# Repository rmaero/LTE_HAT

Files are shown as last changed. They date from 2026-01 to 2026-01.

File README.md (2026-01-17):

4G HAT para Raspberry Pi, Diseño completo de un HAT compatible con Raspberry Pi que integra comunicaciones celulares 4G/LTE. Hecho especialmente para usar como companion computer en y comunicarse con un PixHawk en un UAV (unmanned aerial vehicle).
Desarrollado como proyecto final para la materia Diseño Avanzado de Circuitos Impresos en la Universidad Nacional de Rosario.




Dentro del repositorio se van a encontrar 3 versiones del layout apenas diferentes entre si. Estas iteraciones se hicieron en busqueda de optimizar el espacio y la comodidad de los conectores para el usuario (tener en cuenta que una vez estar montado sobre una Raspberry Pi la cara inferior del HAT no es accesible).

Características

Compatible con estándar Raspberry Pi HAT
Cumple especificaciones mecánicas (65x56mm, mounting holes)
EEPROM de identificación según estándar HAT
Conectores GPIO de 40 pines

Comunicacion UART PixHawk:
Conector JST GH 6 pines para conectar con cable cruzado a GPS2 o TELEM2 del PixHawk Cube Orange. 115200 baudios.

Comunicaciones 4G/LTE:

Módulo celular: SIM7600
Bandas soportadas: [especificar]
Interfaz USB para comandos AT
Conectores SMA/U.FL para antenas externas

Diseño RF de Alta Frecuencia

PCB multicapa: 2 capas (esto fue eleccion adrede como ejercicio academico, porque es mas dificil lograr impedancia controlada con esta distancia entre capas).
Control de impedancia de 50Ω en líneas de RF
Control de impedancia de 90Ω en lineas USB 2.0
Stackup optimizado para señales high-speed
Matching de impedancia en conexiones de antena

Alimentación
Pack de baterias 2S a 9S (de 7V a 35V). Regulador switching para alimentar la Raspberry Pi, segundo regulador switching alimenta el modulo SIM7600.

Tecnologías Utilizadas

Diseño PCB: KiCAD 9
Capas: 2 layers (Ground plane en ambas capas)
Comunicación: USB, UART, SPI, GPIO
Impedancia controlada: 50Ω para trazas RF, 90Ω diferencial para USB

Esquematico principal
Captura de pantalla 2026-01-17 a la(s) 10 48 18
El esquematico completo puede encontrarse en la carpeta del proyecto.

Estado del Proyecto

-Diseño esquemático completo
-Layout PCB con control de impedancia
-Diseño validado en simulación

Estado actual: Proyecto académico completado (2025). Diseño validado, pendiente fabricación y testing.

Licencia
Proyecto académico - Todos los derechos reservados

Contacto
Rodrigo Maero - r.maero@gmail.com

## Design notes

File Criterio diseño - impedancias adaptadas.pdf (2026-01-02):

Antenas de GSM
Por manual del SIM7600, las antenas GSM tienen que tener una impedancia de 50 Ohms. Para lograr esto con 2 layers, cada capa de 2oz de espesor (35 micrones) y 1.5mm de separación, según la simulación de TNT la pista de microstrip tiene que ser de 3mm de espesor.

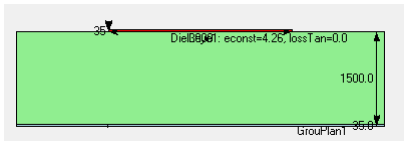
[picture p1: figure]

Characteristic Impedance (Ohms):
For Signal Line ::RectCond1R0= 49.188

No es posible aplicar esto en el layout.
Una opción sería cambiar a 4 layers para tener el plano de retorno más cercano. Con una separación de 250 micrones con el plano de retorno, se necesita una microstrip de 450 micrones de ancho (0.45mm)

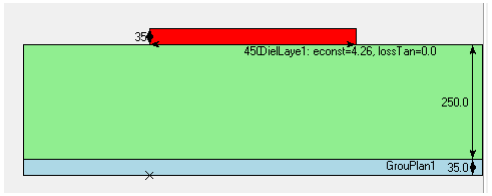
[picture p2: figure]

Characteristic Impedance (Ohms):
For Signal Line ::RectCond1R0= 51.1073

Una opción para mantener el stackup de 2 capas es utilizar una guía de onda coplanar con plano de masa (coplanar waveguide with ground). Se tiene en cuenta la masa rodeando la microstrip con una separación estricta y se rodea con vias al plano de la otra capa para disminuir la impedancia.
https://www.nwengineeringllc.com/article/coplanar-waveguide-design-for-your-rf-pcb.phphttps://electronics.stackexchange.com/questions/87473/how-to-design-a-pcb-to-co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 (https://electronics.stackexchange.com/questions/87473/how-to-design-a-pcb-to-connect-the-gsm-modem-with-50ohm-track-impedance)

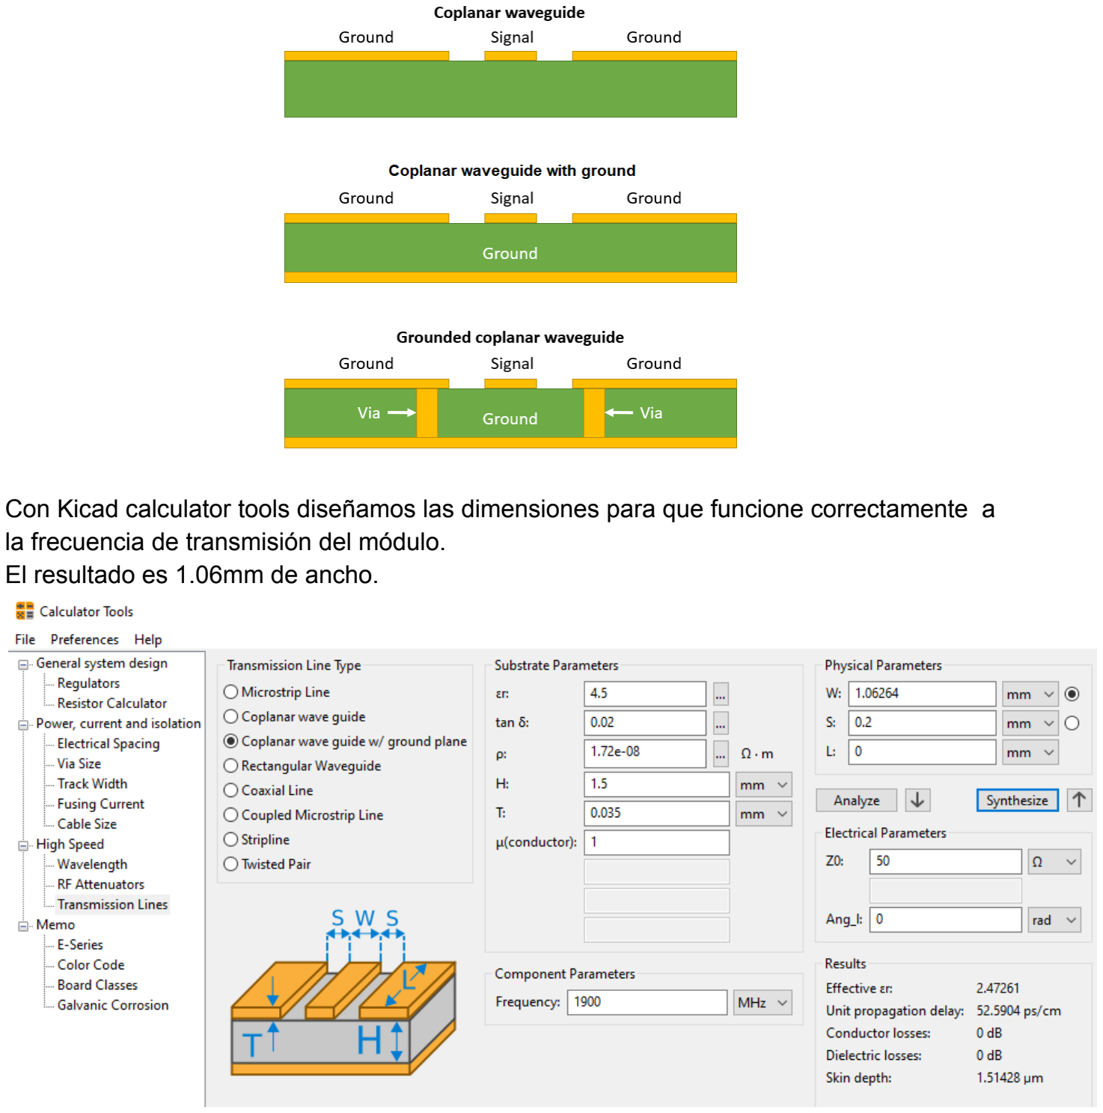
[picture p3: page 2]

Con Kicad calculator tools diseñamos las dimensiones para que funcione correctamente a la frecuencia de transmisión del módulo.
El resultado es 1.06mm de ancho.

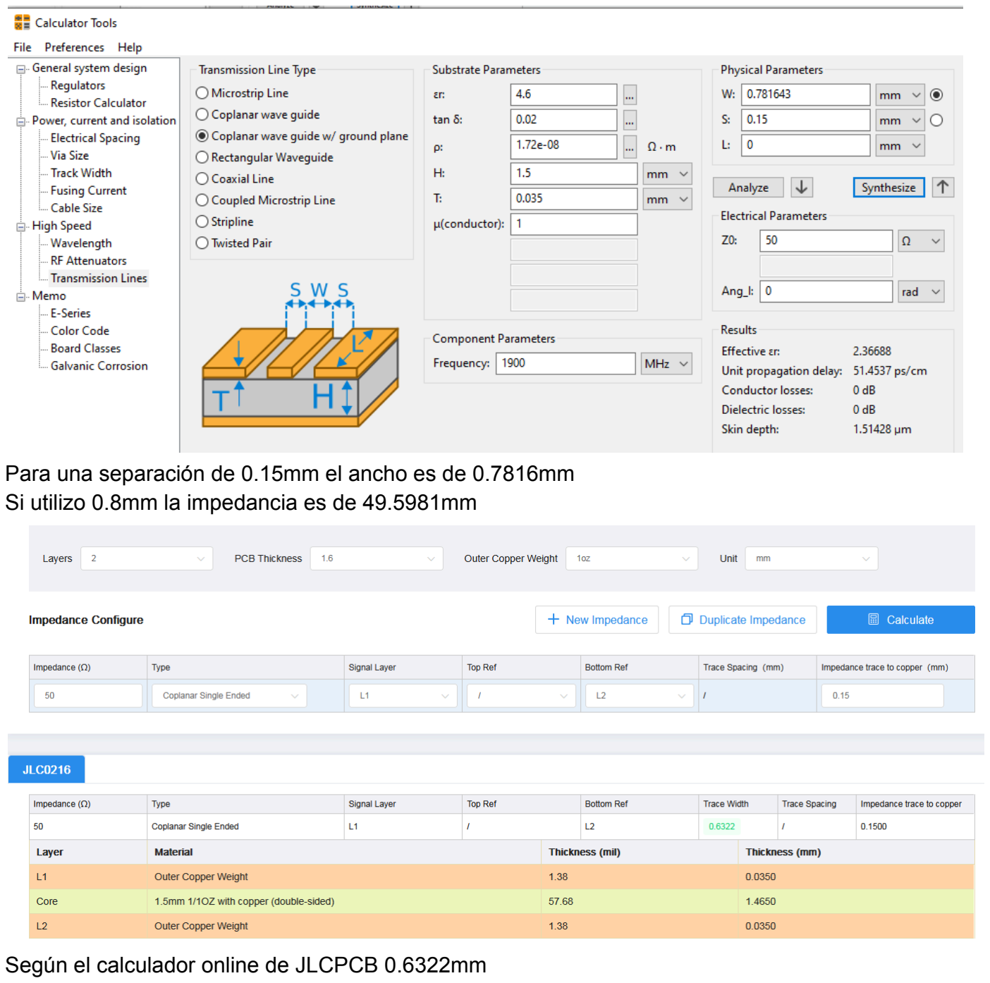
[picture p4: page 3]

Para una separación de 0.15mm el ancho es de 0.7816mm Si utilizo 0.8mm la impedancia es de 49.5981mm

Según el calculador online de JLCPCB 0.6322mm

Ruteo de la antena:

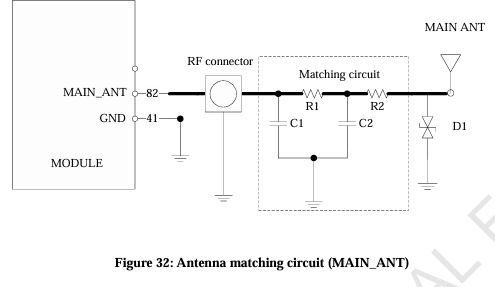
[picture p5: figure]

Del datasheet del modulo SIM7600:
In above figure, the components R1, C1, C2 and R2 are used for antenna matching. By default, the R1, R2 are 0Ω resistors, and the C1, C2 are reserved for tuning.

Se rutea un conector de antena secundario (J230) para poder medir la impedancia de la pista, y en caso de ser necesario se agregan los elementos pasivos R230,R231,C230,C231 para ajustar la impedancia a 50 Ohms.

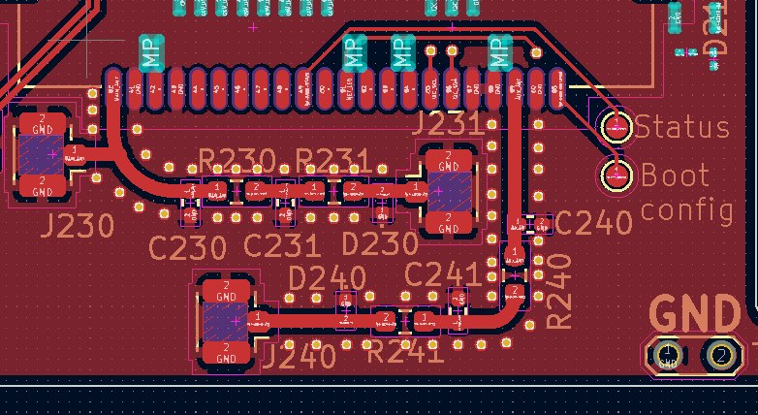
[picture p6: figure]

La línea de transmisión se diseñó curva para evitar ángulos rectos y se agregó via stitching para reducir la impedancia de masa entre las dos capas. No sé qué tan necesarias son estas cosas.

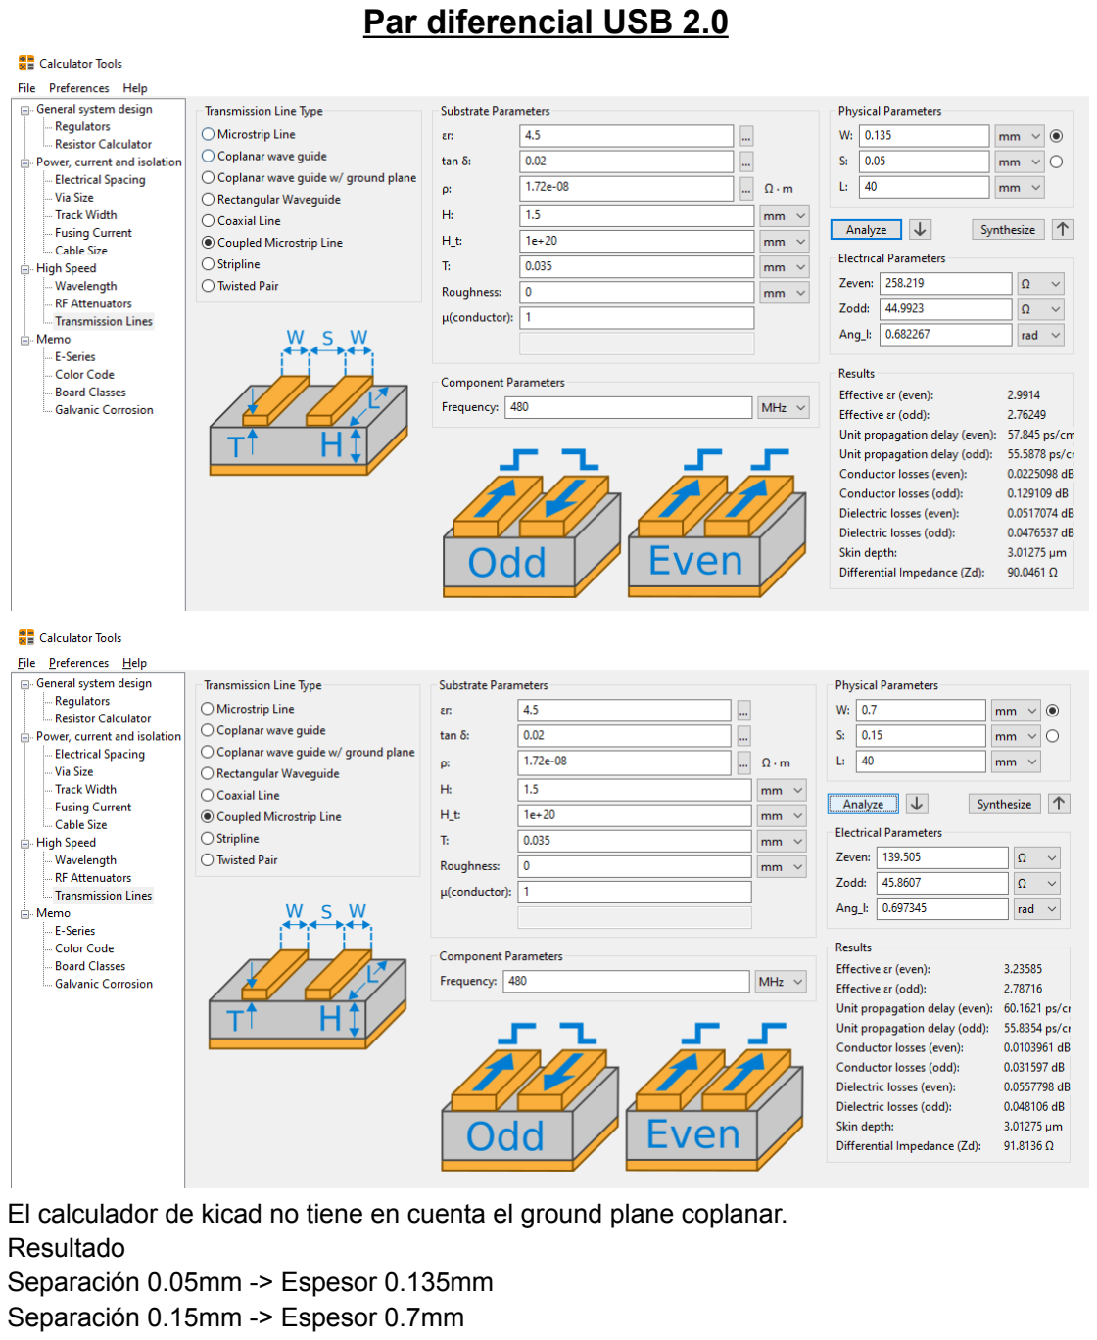
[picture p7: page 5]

### Par diferencial USB 2.0

El calculador de kicad no tiene en cuenta el ground plane coplanar. Resultado
Separación 0.05mm -> Espesor 0.135mm
Separación 0.15mm -> Espesor 0.7mm

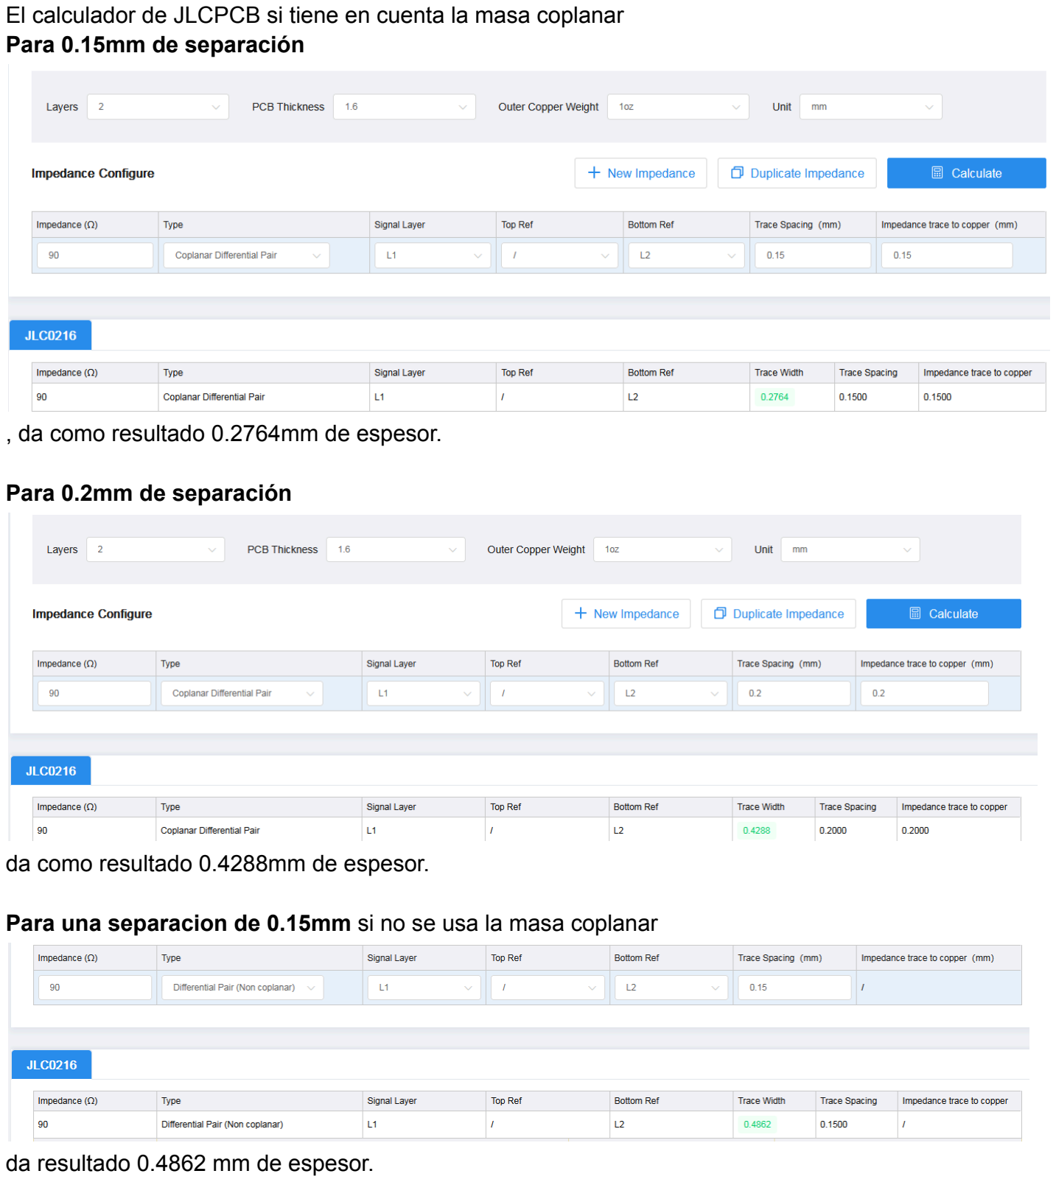
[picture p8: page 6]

El calculador de JLCPCB si tiene en cuenta la masa coplanar Para 0.15mm de separación

, da como resultado 0.2764mm de espesor.

Para 0.2mm de separación

da como resultado 0.4288mm de espesor.

Para una separacion de 0.15mm si no se usa la masa coplanar

da resultado 0.4862 mm de espesor.

Ruteo del par diferencial
Dada la posición elegida del puerto USB en la primer versión, el par diferencial atraviesa discontinuidades en el plano de masa de la capa inferior. Debería tener un plano de masa ininterrumpido para asegurar la impedancia calculada.

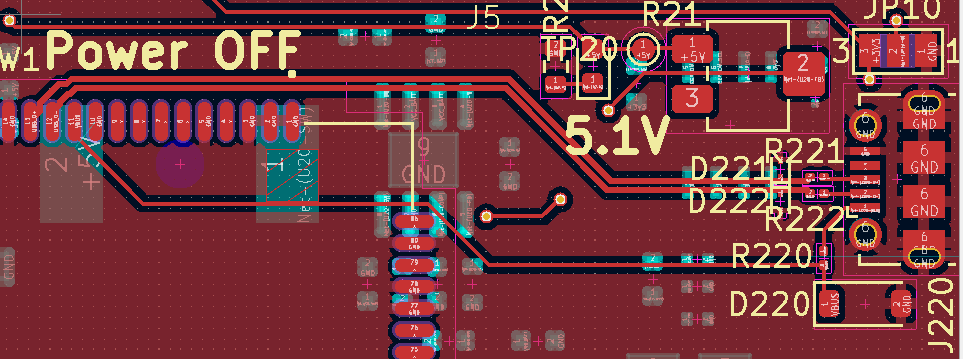
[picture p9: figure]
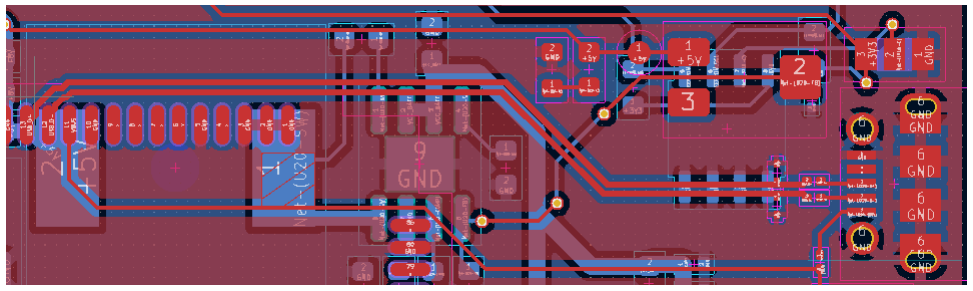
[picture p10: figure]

C

a

m

bia

m

o

s la

p

o

sició

n

d

el p

u

e

r

t

o

al in

f

e

rio

r

d

e la

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
el pla

n

o ininterrumpido.

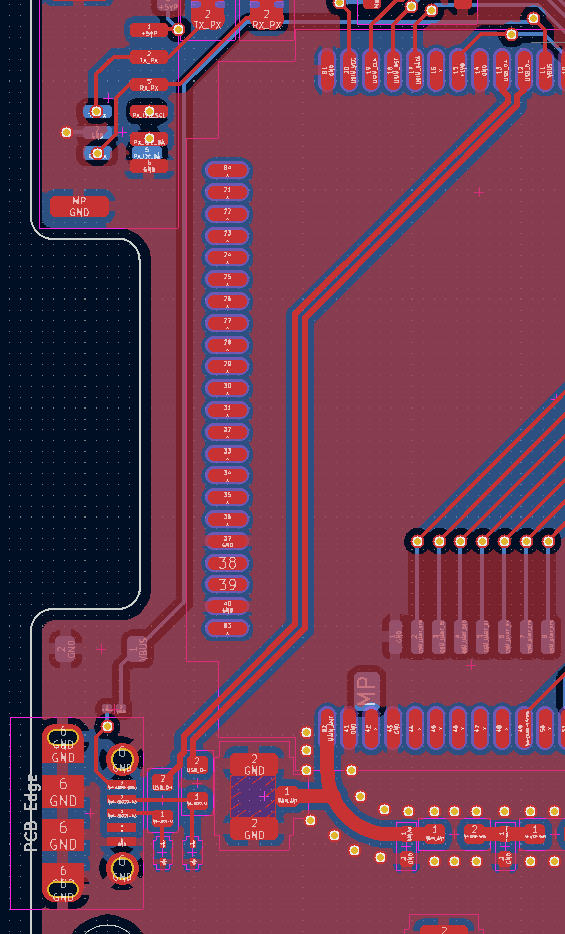
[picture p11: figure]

Version final

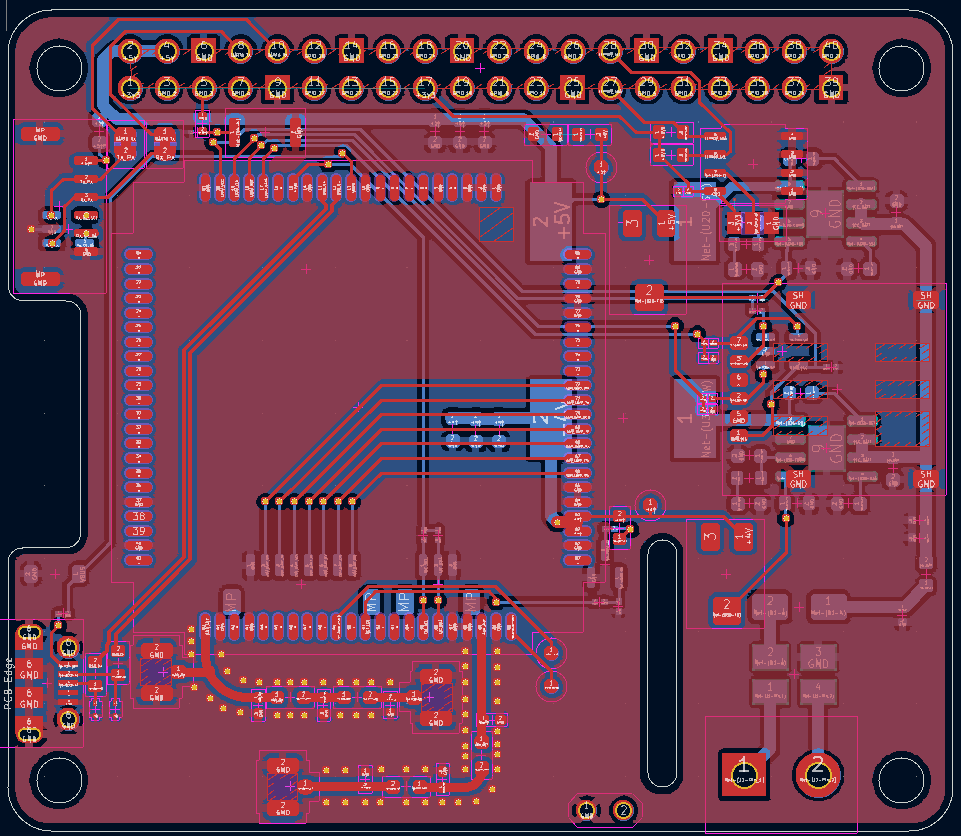
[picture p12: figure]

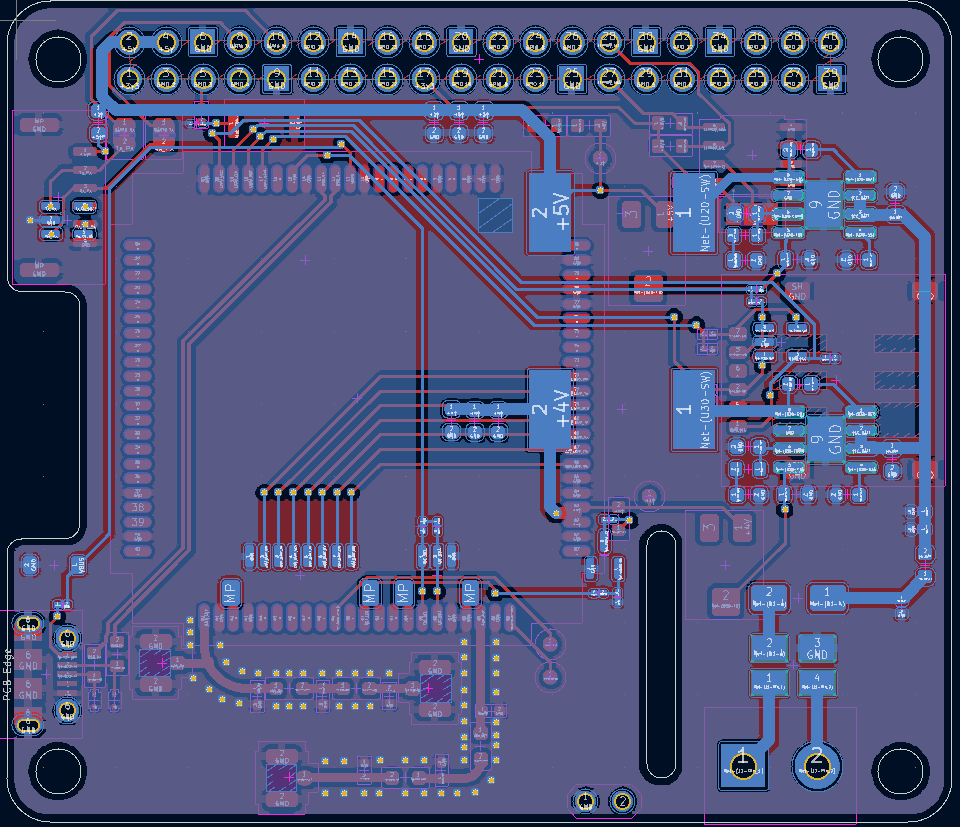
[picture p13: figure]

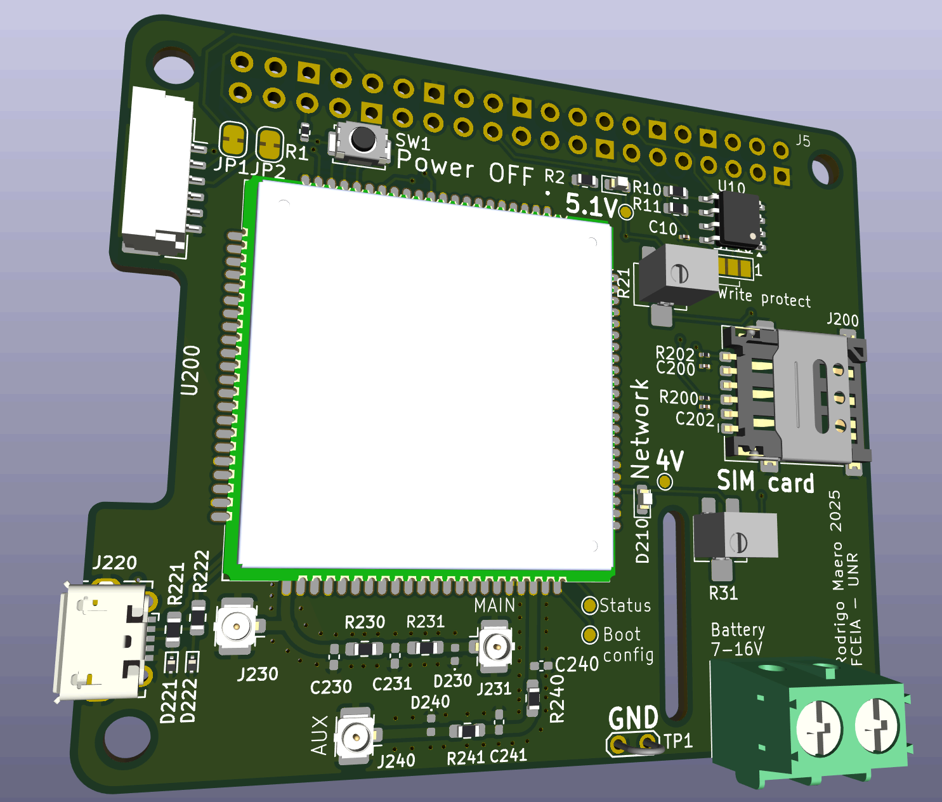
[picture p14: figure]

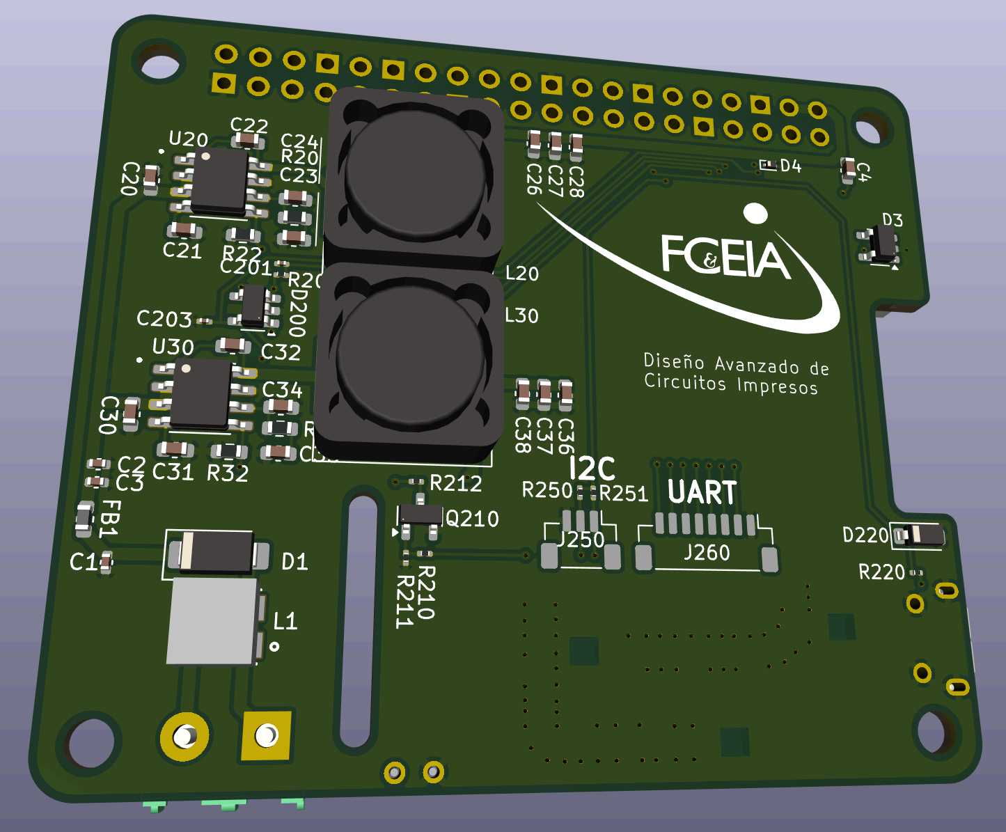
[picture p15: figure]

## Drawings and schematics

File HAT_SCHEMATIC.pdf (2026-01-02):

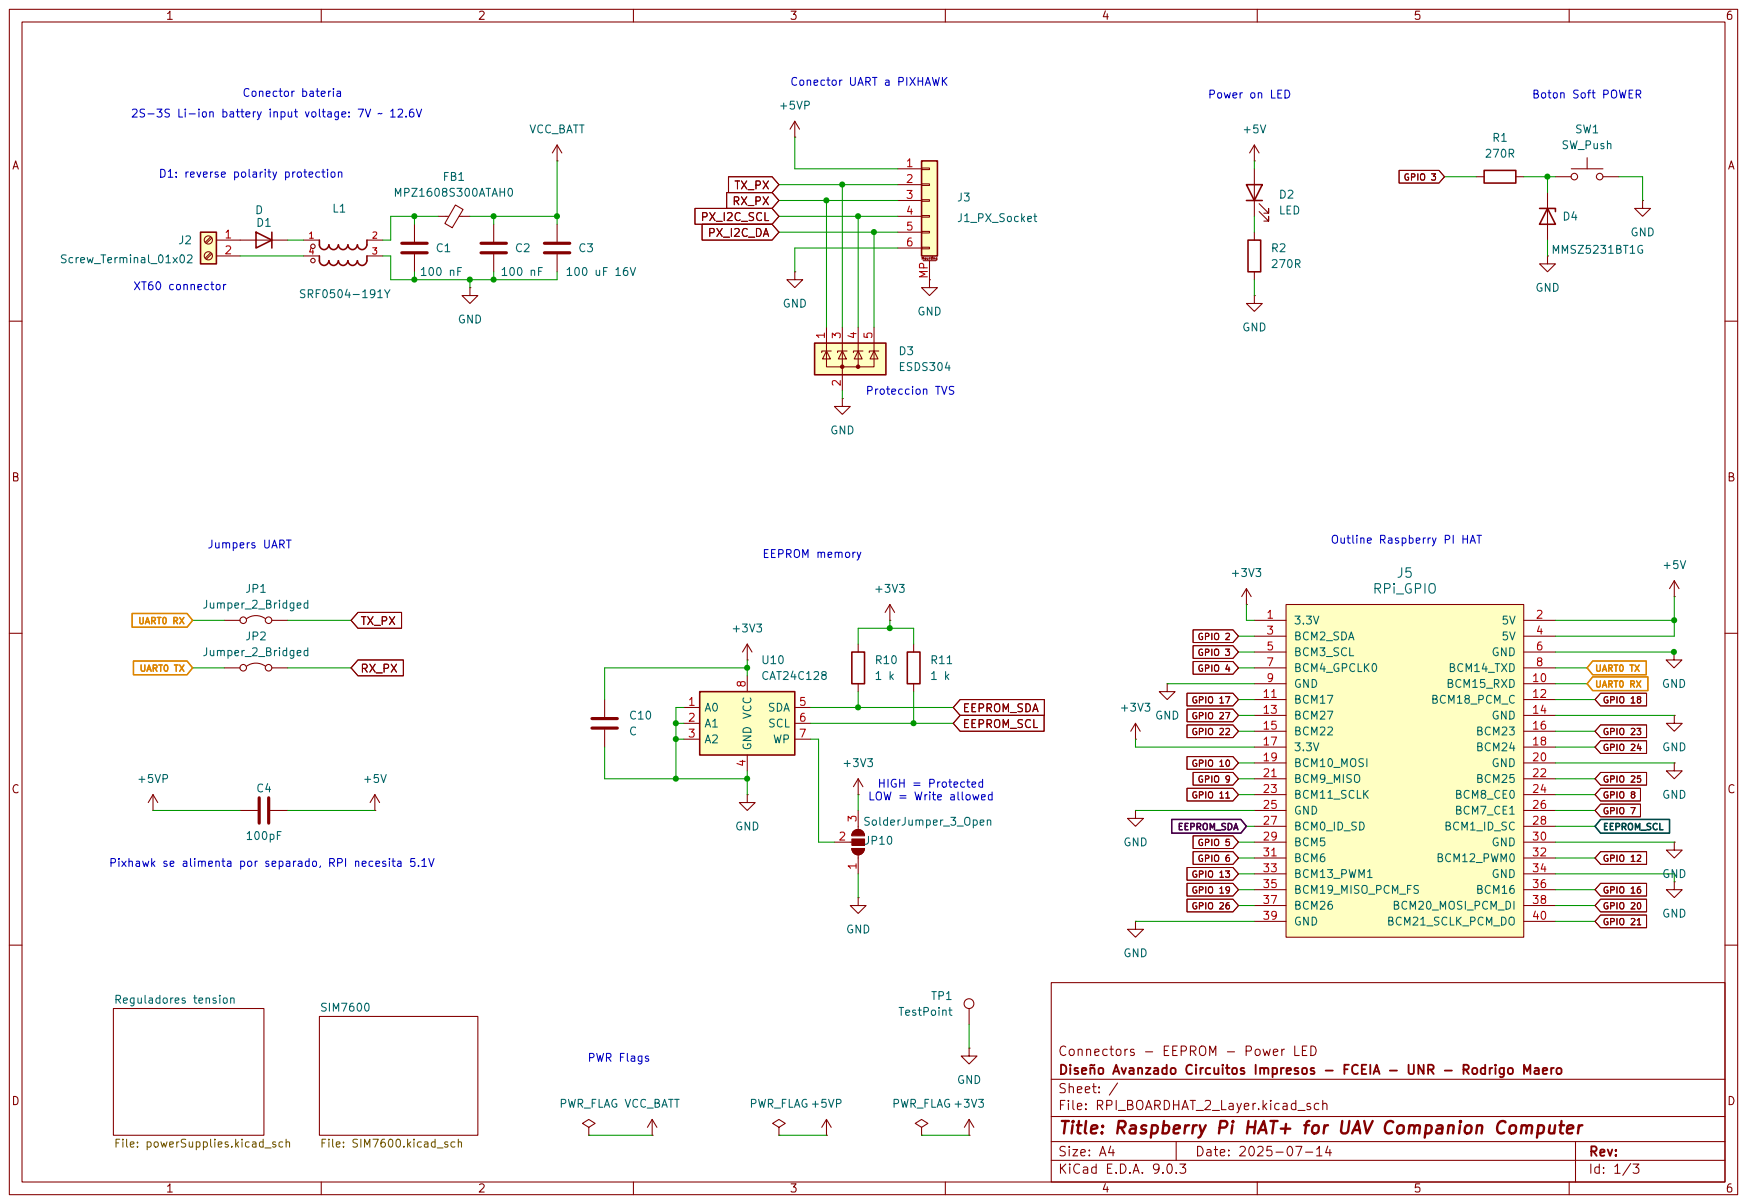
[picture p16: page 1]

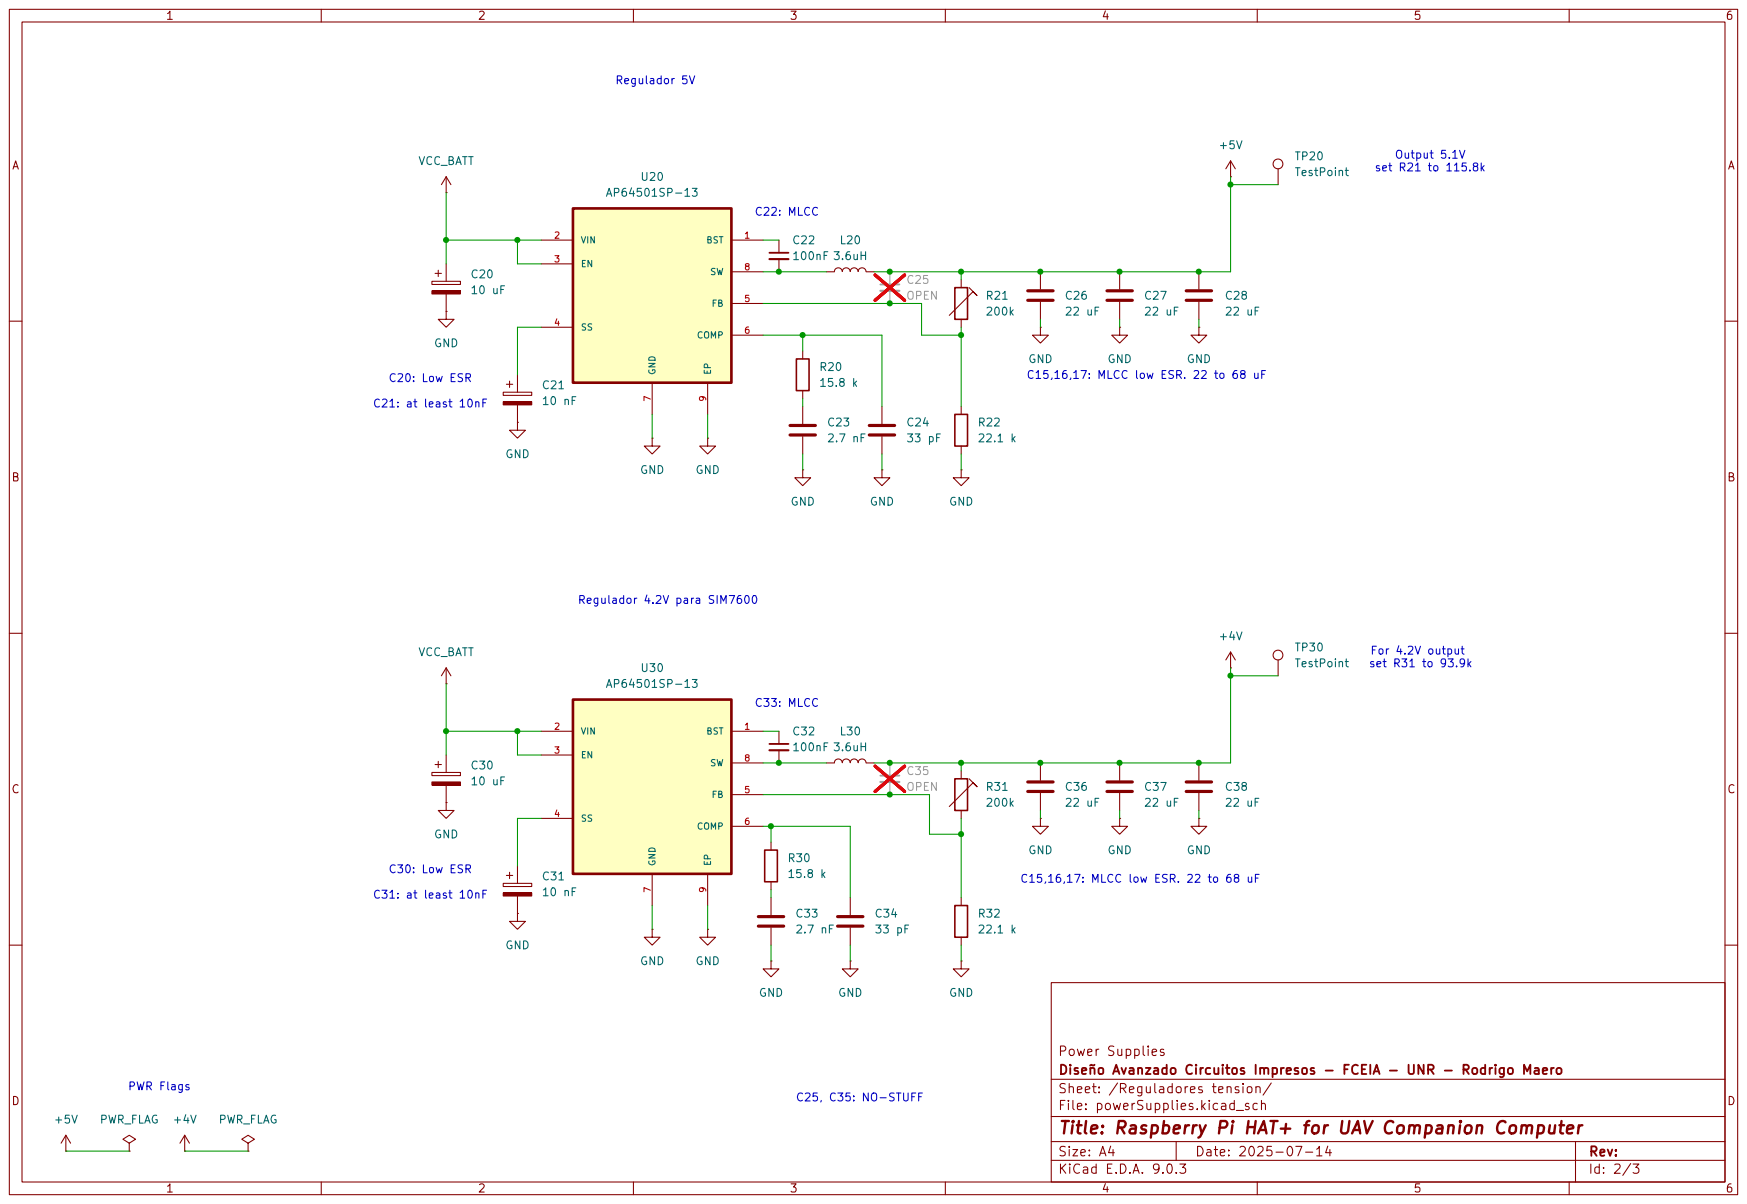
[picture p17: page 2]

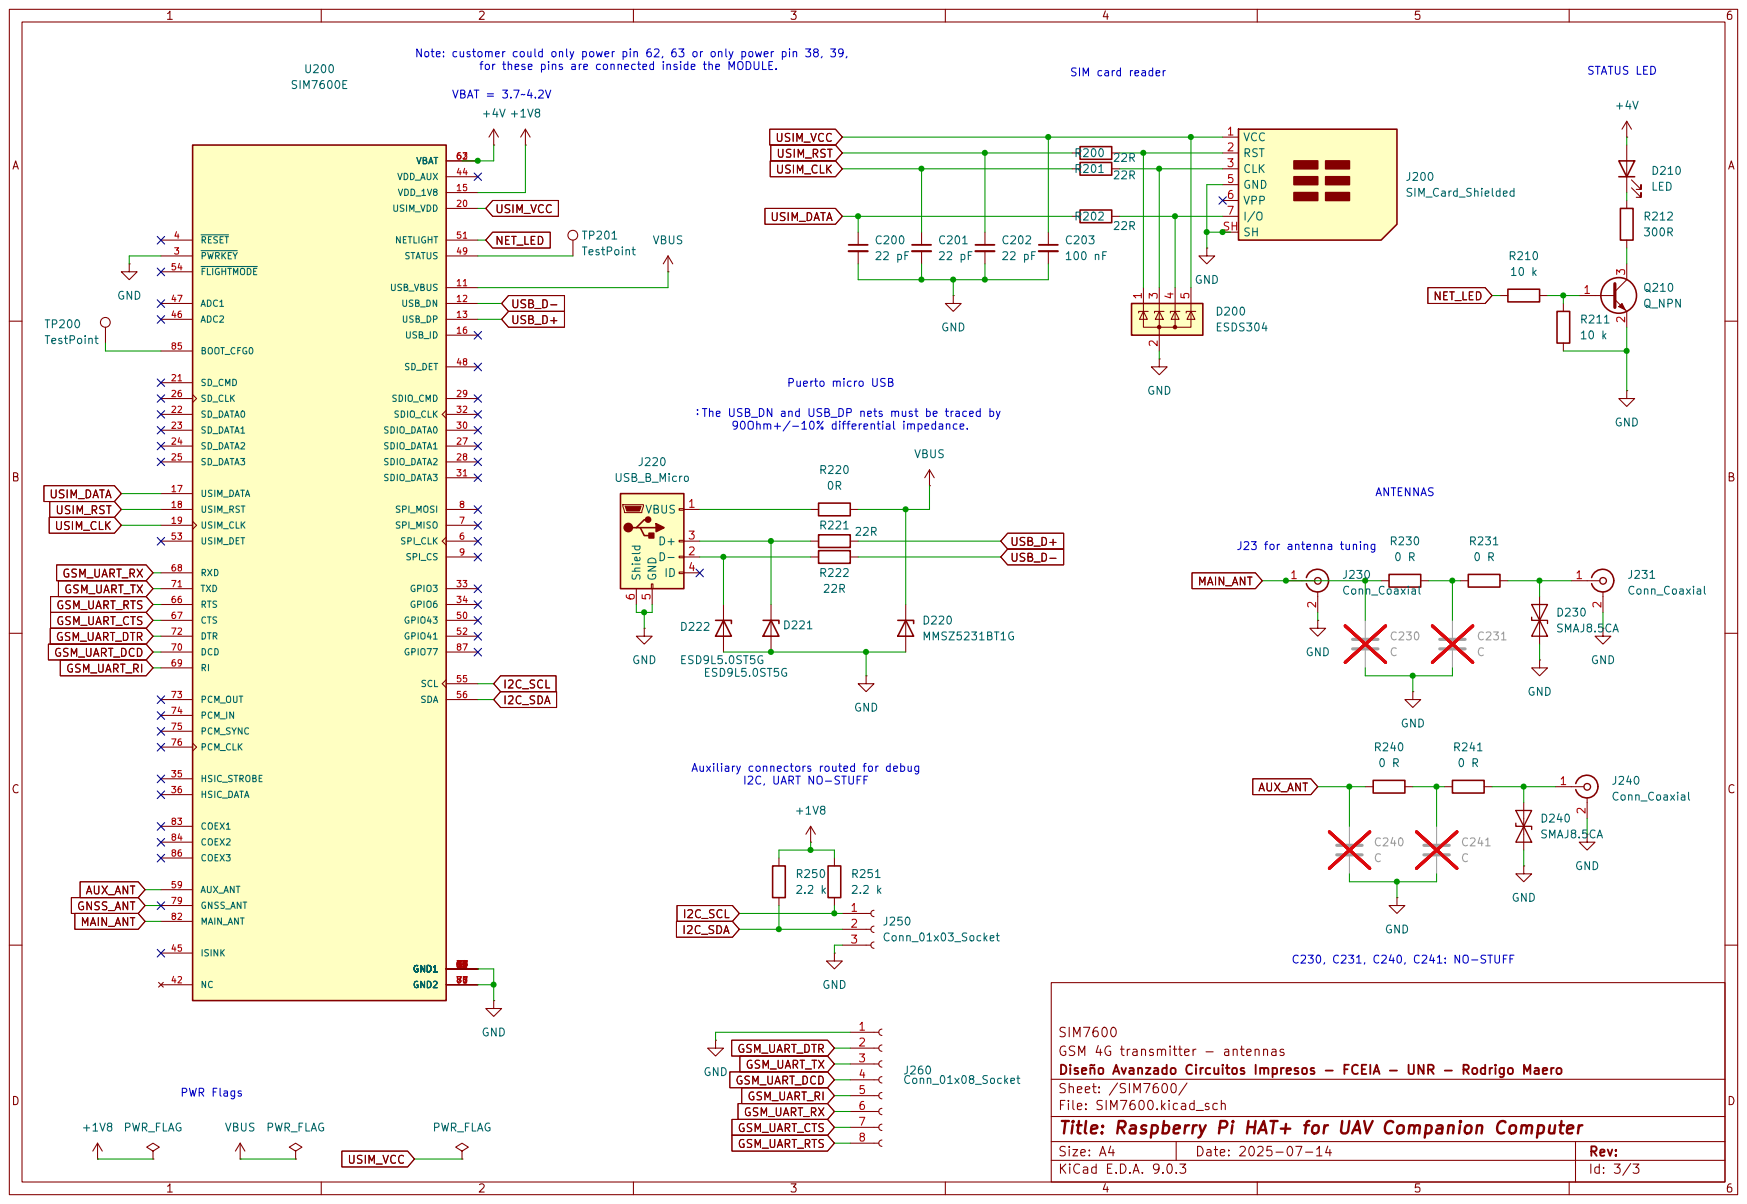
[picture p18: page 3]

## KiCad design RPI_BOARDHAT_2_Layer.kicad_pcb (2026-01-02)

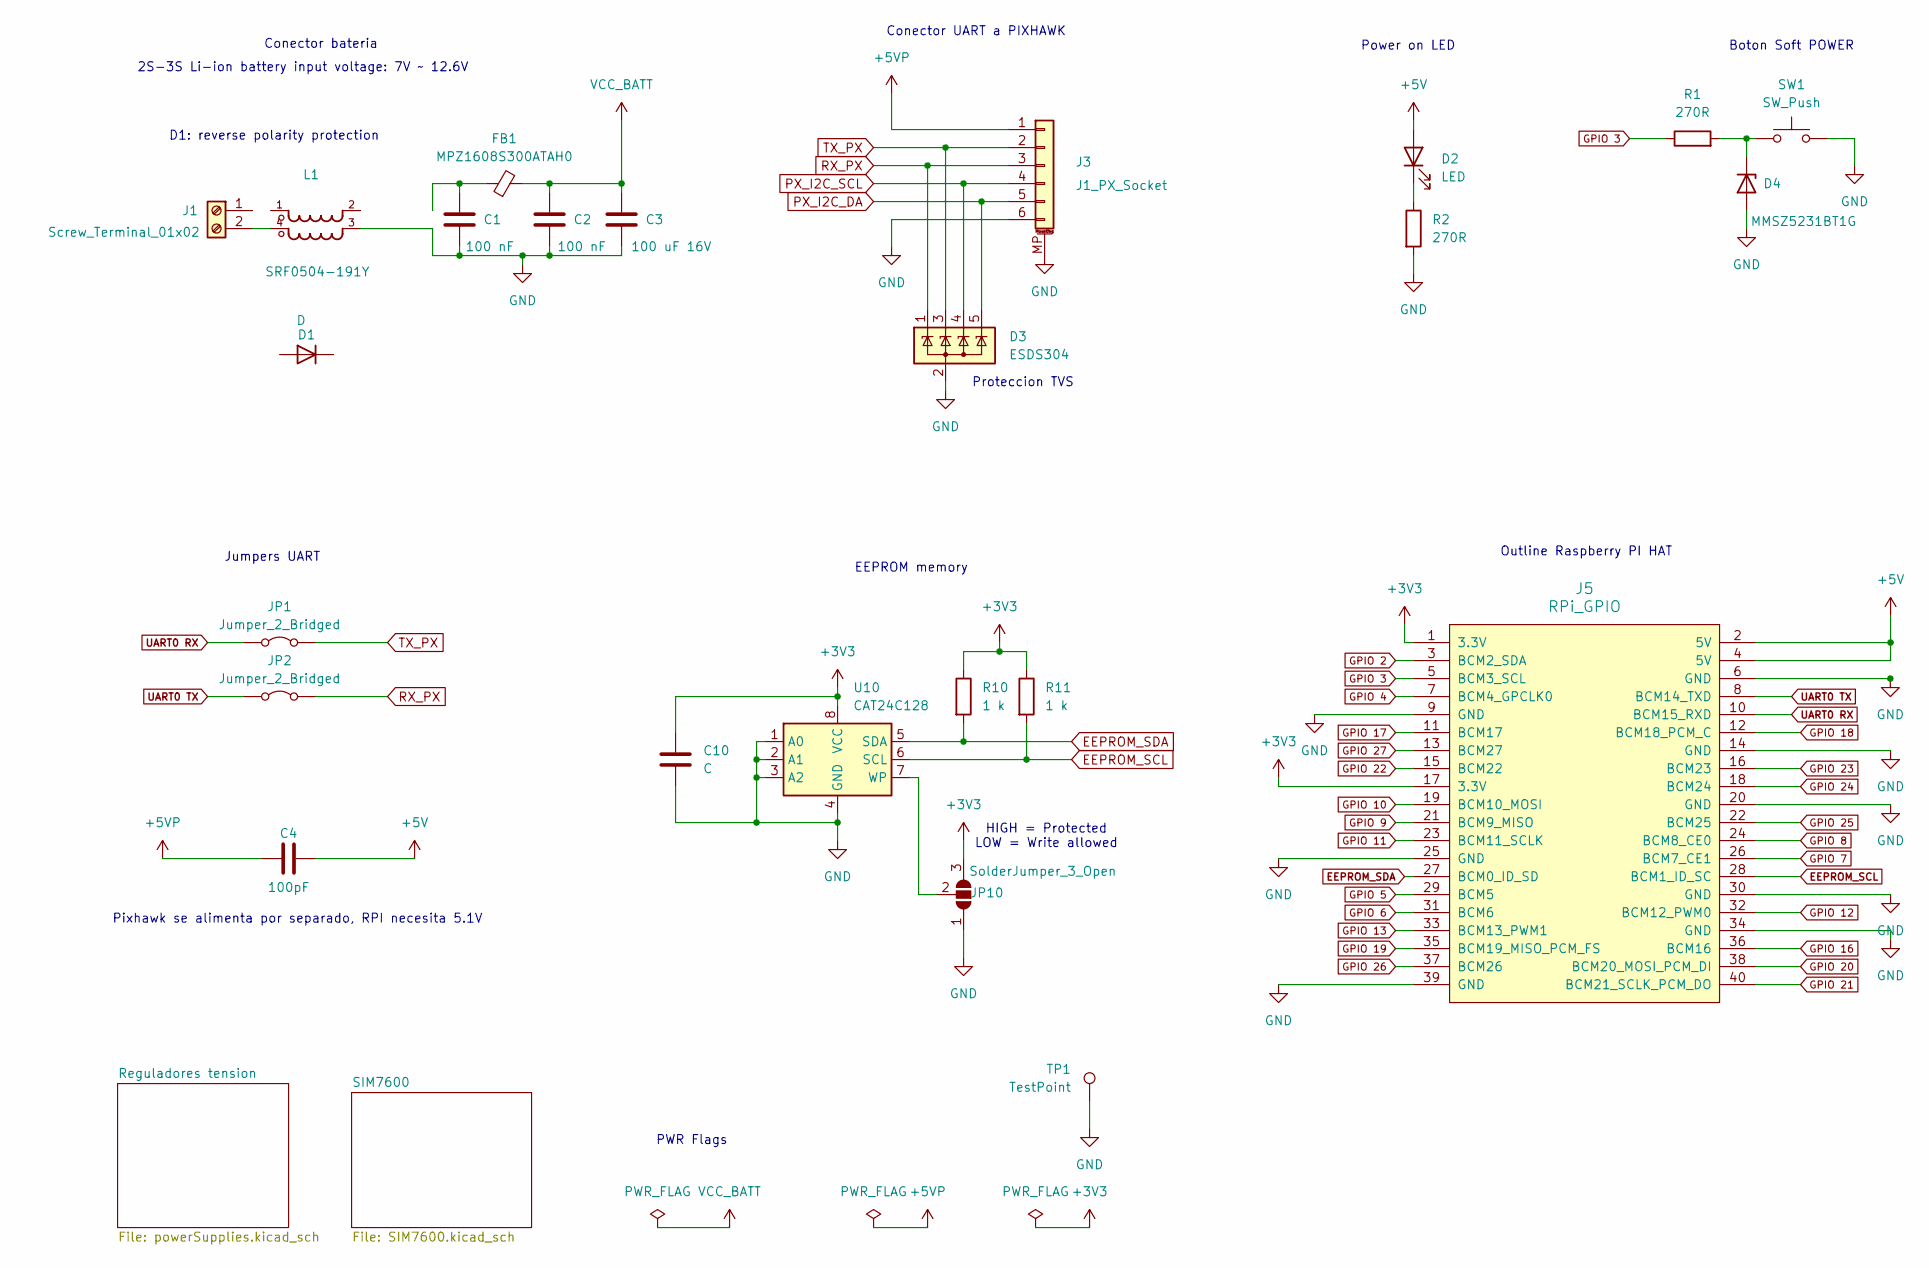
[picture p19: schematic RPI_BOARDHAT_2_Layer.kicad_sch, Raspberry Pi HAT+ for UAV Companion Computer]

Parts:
C1, C2: 100 nF; C_0402_1005Metric
C3: 100 uF 16V; C_0402_1005Metric
C4: 100pF; C_0603_1608Metric
C10: C; C_0201_0603Metric
D1: D; D_SMA
D2: LED; LED_0603_1608Metric
D3: ESDS304; SOT-23-5
D4: MMSZ5231BT1G; D_SOD-923
FB1: MPZ1608S300ATAH0; L_0603_1608Metric
J1: Screw_Terminal_01x02; TerminalBlock_bornier-2_P5.08mm
J3: J1_PX_Socket; JST_GH_SM06B-GHS-TB_1x06-1MP_P1.25mm_Horizontal
J5: RPi_GPIO; RPI_Hat_B+
JP1, JP2: Jumper_2_Bridged; SolderJumper-2_P1.3mm_Bridged_RoundedPad1.0x1.5mm
JP10: SolderJumper_3_Open; SolderJumper-3_P1.3mm_Open_Pad1.0x1.5mm_NumberLabels
L1: SRF0504-191Y; FIL_SRF0504-191Y
R1: 270R; R_0201_0603Metric
R2: 270R; R_0603_1608Metric
R10, R11: 1 k; R_0603_1608Metric
SW1: SW_Push; SW_Push_SPST_NO_Alps_SKRK
TP1: TestPoint; TestPoint_2Pads_Pitch2.54mm_Drill0.8mm
U10: CAT24C128; JEITA_SOIC-8_3.9x4.9mm_P1.27mm

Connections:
+3V3: C10.1, J5.1 (3.3V), J5.17 (3.3V), JP10.3 (B), R10.1, R11.1, U10.8 (VCC)
+5V: C4.1, D2.2 (A), J5.2 (5V), J5.4 (5V); also elsewhere on the board
+5VP: C4.2, J3.1
EEPROM_SCL: J5.28 (BCM1_ID_SC), R11.2, U10.6 (SCL)
EEPROM_SDA: J5.27 (BCM0_ID_SD), R10.2, U10.5 (SDA)
GND: C1.2, C2.2, C3.2, C10.2, D3.2 (A), D4.2 (A), J3.6, J3.MP (MountPin), J5.6 (GND), J5.9 (GND), J5.14 (GND), J5.20 (GND), J5.25 (GND), J5.30 (GND), J5.34 (GND), J5.39 (GND), JP10.1 (A), L1.3, R2.2, SW1.2, TP1.1, U10.1 (A0), U10.2 (A1), U10.3 (A2), U10.4 (GND); also elsewhere on the board
GPIO 2: J5.3 (BCM2_SDA)
GPIO 3: J5.5 (BCM3_SCL), R1.1
GPIO 4: J5.7 (BCM4_GPCLK0)
GPIO 5: J5.29 (BCM5)
GPIO 6: J5.31 (BCM6)
GPIO 7: J5.26 (BCM7_CE1)
GPIO 8: J5.24 (BCM8_CE0)
GPIO 9: J5.21 (BCM9_MISO)
GPIO 10: J5.19 (BCM10_MOSI)
GPIO 11: J5.23 (BCM11_SCLK)
GPIO 12: J5.32 (BCM12_PWM0)
GPIO 13: J5.33 (BCM13_PWM1)
GPIO 16: J5.36 (BCM16)
GPIO 17: J5.11 (BCM17)
GPIO 18: J5.12 (BCM18_PCM_C)
GPIO 19: J5.35 (BCM19_MISO_PCM_FS)
GPIO 20: J5.38 (BCM20_MOSI_PCM_DI)
GPIO 21: J5.40 (BCM21_SCLK_PCM_DO)
GPIO 22: J5.15 (BCM22)
GPIO 23: J5.16 (BCM23)
GPIO 24: J5.18 (BCM24)
GPIO 25: J5.22 (BCM25)
GPIO 26: J5.37 (BCM26)
GPIO 27: J5.13 (BCM27)
unnamed: D1.2 (A), L1.2
unnamed: D2.1 (K), R2.1
unnamed: D4.1 (K), R1.2, SW1.1
unnamed: J1.1, L1.1
unnamed: J1.2, L1.4
unnamed: JP10.2 (C), U10.7 (WP)
PX_I2C_DA: D3.5 (K), J3.5
PX_I2C_SCL: D3.4 (K), J3.4
RX_PX: D3.1 (K), J3.3, JP2.2 (B)
TX_PX: D3.3 (K), J3.2, JP1.2 (B)
UART0 RX: J5.10 (BCM15_RXD), JP1.1 (A)
UART0 TX: J5.8 (BCM14_TXD), JP2.1 (A)
VCC_BATT: C2.1, C3.1, FB1.2; also elsewhere on the board

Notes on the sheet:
2S-3S Li-ion battery input voltage: 7V ~ 12.6V
Proteccion TVS
PWR Flags
Pixhawk se alimenta por separado, RPI necesita 5.1V
D1: reverse polarity protection
EEPROM memory
Outline Raspberry PI HAT
Conector UART a PIXHAWK
Jumpers UART
HIGH = Protected LOW = Write allowed
Boton Soft POWER
Conector bateria
Power on LED

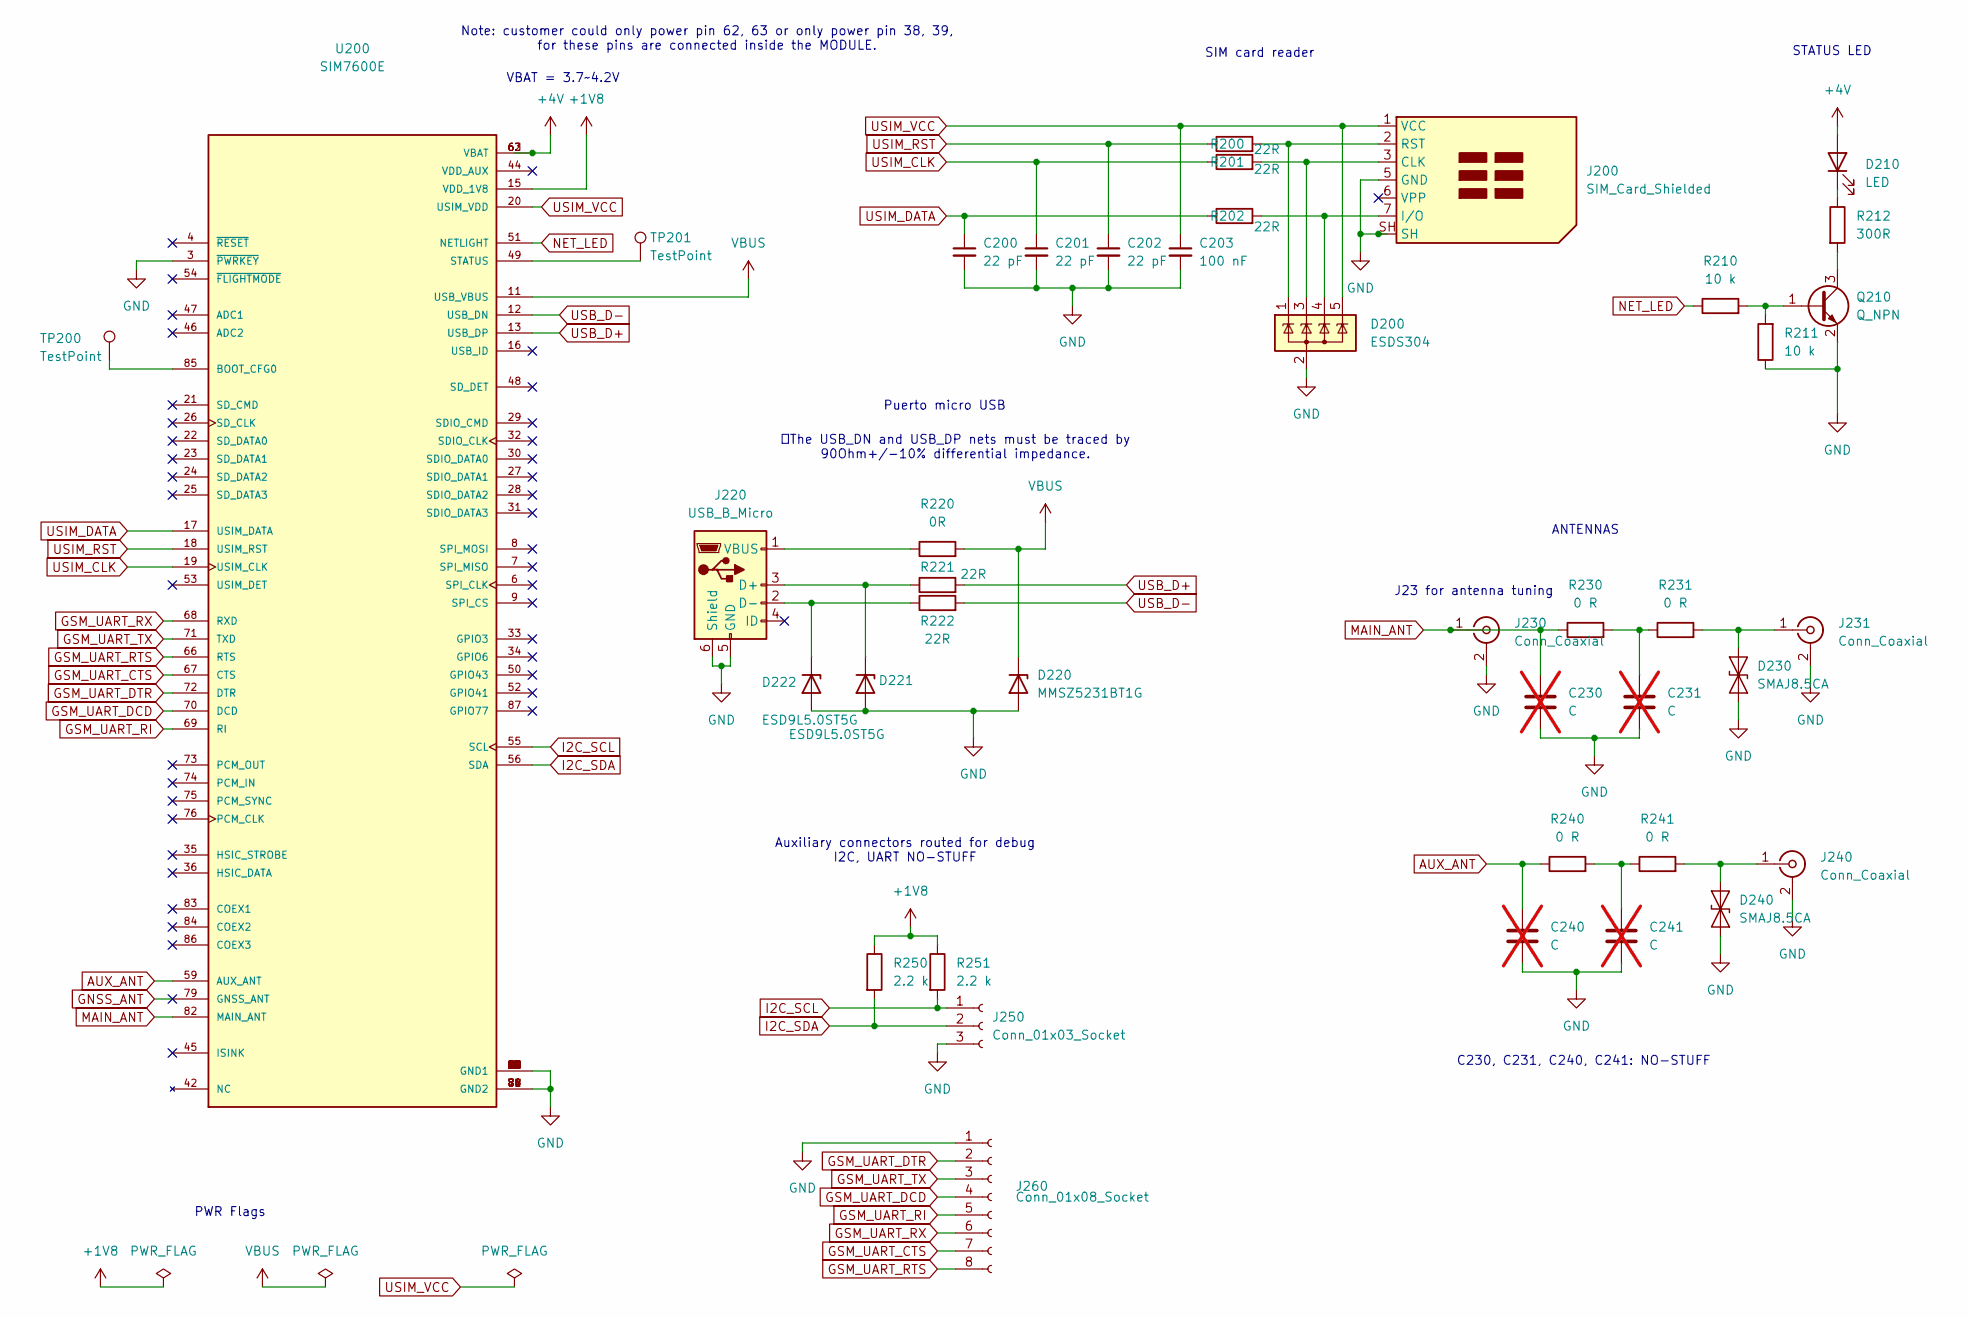
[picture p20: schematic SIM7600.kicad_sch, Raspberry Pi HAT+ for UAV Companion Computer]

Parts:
C200, C201, C202: 22 pF; C_0201_0603Metric
C203: 100 nF; C_0201_0603Metric
C230, C231, C240, C241: C; C_0402_1005Metric_Pad0.74x0.62mm_HandSolder; not fitted
D200: ESDS304; SOT-23-5
D210: LED; LED_0603_1608Metric
D220: MMSZ5231BT1G; D_SOD-123
D221, D222: ESD9L5.0ST5G; D_SOD-923
D230, D240: SMAJ8.5CA; D_0402_1005Metric
J200: SIM_Card_Shielded; nanoSIM_GCT_SIM8060-6-0-14-00
J220: USB_B_Micro; USB_Micro-B_Molex-105017-0001
J230, J231, J240: Conn_Coaxial; U.FL_Hirose_U.FL-R-SMT-1_Vertical
J250: Conn_01x03_Socket; JST_SH_BM03B-SRSS-TB_1x03-1MP_P1.00mm_Vertical
J260: Conn_01x08_Socket; JST_SH_BM08B-SRSS-TB_1x08-1MP_P1.00mm_Vertical
Q210: Q_NPN; SOT-23
R200, R201, R202: 22R; R_0201_0603Metric
R210, R211: 10 k; R_0201_0603Metric
R212: 300R; R_0201_0603Metric
R220: 0R; R_0201_0603Metric
R221, R222: 22R; R_0603_1608Metric
R230, R231, R240, R241: 0 R; R_0603_1608Metric_Pad0.98x0.95mm_HandSolder
R250, R251: 2.2 k; R_0201_0603Metric
TP200, TP201: TestPoint; TestPoint_Pad_D1.0mm
U200: SIM7600E; XCVR_SIM7600E; PARTREV V1.03

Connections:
+1V8: R250.1, R251.1, U200.15 (VDD_1V8)
+4V: D210.2 (A), U200.62 (VBAT), U200.63 (VBAT); also elsewhere on the board
AUX_ANT: C240.1, R240.1, U200.59 (AUX_ANT)
GND: C200.2, C201.2, C202.2, C203.2, C230.2, C231.2, C240.2, C241.2, D200.2 (A), D220.2 (A), D221.2 (A), D222.2 (A), D230.1 (A1), D240.1 (A1), J200.5 (GND), J200.SH, J220.5 (GND), J220.6 (Shield), J230.2 (Ext), J231.2 (Ext), J240.2 (Ext), J250.3, J260.1, Q210.2 (E), R211.1, U200.1 (GND1), U200.2 (GND1), U200.3 (~PWRKEY), U200.5 (GND1), U200.10 (GND1), U200.14 (GND1), U200.37 (GND1), U200.40 (GND1), U200.41 (GND1), U200.43 (GND1), U200.57 (GND1), U200.58 (GND1), U200.60 (GND1), U200.61 (GND1), U200.64 (GND1), U200.65 (GND1), U200.77 (GND2), U200.78 (GND2), U200.80 (GND2), U200.81 (GND2); also elsewhere on the board
GNSS_ANT: U200.79 (GNSS_ANT)
GSM_UART_CTS: J260.7, U200.67 (CTS)
GSM_UART_DCD: J260.4, U200.70 (DCD)
GSM_UART_DTR: J260.2, U200.72 (DTR)
GSM_UART_RI: J260.5, U200.69 (RI)
GSM_UART_RTS: J260.8, U200.66 (RTS)
GSM_UART_RX: J260.6, U200.68 (RXD)
GSM_UART_TX: J260.3, U200.71 (TXD)
I2C_SCL: J250.1, R251.2, U200.55 (SCL)
I2C_SDA: J250.2, R250.2, U200.56 (SDA)
MAIN_ANT: C230.1, J230.1 (In), R230.1, U200.82 (MAIN_ANT)
NET_LED: R210.1, U200.51 (NETLIGHT)
unnamed: C231.1, R230.2, R231.1
unnamed: C241.1, R240.2, R241.1
unnamed: D210.1 (K), R212.1
unnamed: D221.1 (K), J220.3 (D+), R221.1
unnamed: D222.1 (K), J220.2 (D-), R222.1
unnamed: D230.2 (A2), J231.1 (In), R231.2
unnamed: D240.2 (A2), J240.1 (In), R241.2
unnamed: D200.3 (K), J200.3 (CLK), R201.2
unnamed: D200.4 (K), J200.7 (I/O), R202.2
unnamed: D200.1 (K), J200.2 (RST), R200.2
unnamed: J220.1 (VBUS), R220.1
unnamed: Q210.1 (B), R210.2, R211.2
unnamed: Q210.3 (C), R212.2
unnamed: TP200.1, U200.85 (BOOT_CFG0)
unnamed: TP201.1, U200.49 (STATUS)
USB_D+: R221.2, U200.13 (USB_DP)
USB_D-: R222.2, U200.12 (USB_DN)
USIM_CLK: C201.1, R201.1, U200.19 (USIM_CLK)
USIM_DATA: C200.1, R202.1, U200.17 (USIM_DATA)
USIM_RST: C202.1, R200.1, U200.18 (USIM_RST)
USIM_VCC: C203.1, D200.5 (K), J200.1 (VCC), U200.20 (USIM_VDD)
VBUS: D220.1 (K), R220.2, U200.11 (USB_VBUS)

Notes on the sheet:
SIM card reader
Auxiliary connectors routed for debug I2C, UART NO-STUFF
STATUS LED
Puerto micro USB
VBAT = 3.7~4.2V
PWR Flags
C230, C231, C240, C241: NO-STUFF
Note: customer could only power pin 62, 63 or only power pin 38, 39, for these pins are connected inside the MODULE.
ANTENNAS
J23 for antenna tuning
：The USB_DN and USB_DP nets must be traced by 90Ohm+/-10% differential impedance.

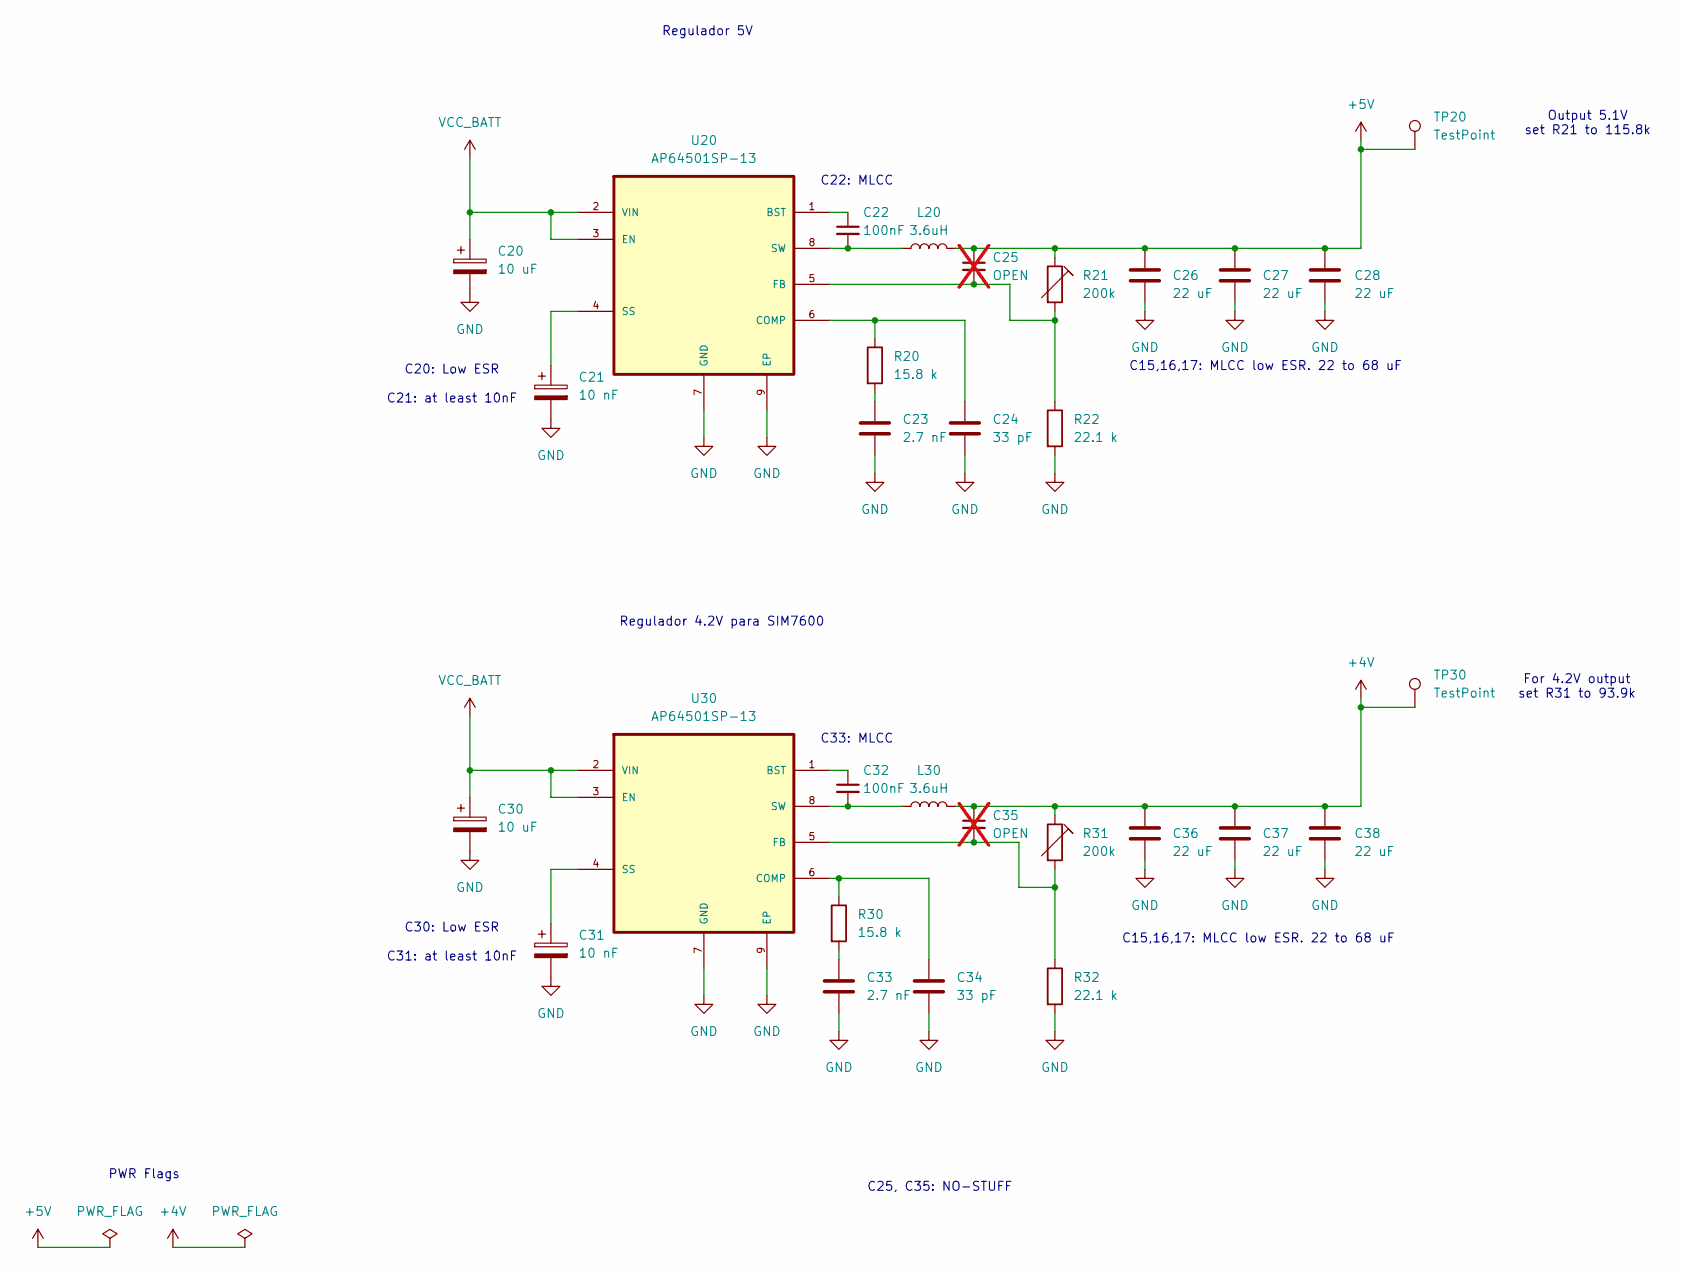
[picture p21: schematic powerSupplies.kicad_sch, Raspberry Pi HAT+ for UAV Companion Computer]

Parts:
C20, C30: 10 uF; C_0603_1608Metric
C21, C31: 10 nF; C_0603_1608Metric
C22, C32: 100nF; C_0603_1608Metric
C23, C33: 2.7 nF; C_0603_1608Metric
C24, C34: 33 pF; C_0603_1608Metric
C25, C35: OPEN; C_0201_0603Metric; not fitted
C26, C27, C28, C36, C37, C38: 22 uF; C_0603_1608Metric
L20, L30: 3.6uH; L_12x12mm_H8mm
R20, R30: 15.8 k; R_0603_1608Metric
R21, R31: 200k; Potentiometer_Bourns_3214X_Vertical
R22, R32: 22.1 k; R_0603_1608Metric
TP20, TP30: TestPoint; TestPoint_Pad_D1.0mm
U20, U30: AP64501SP-13; SOIC127P600X170-9N

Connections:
+4V: C35.1, C36.1, C37.1, C38.1, L30.2, R31.1, TP30.1; also elsewhere on the board
+5V: C25.1, C26.1, C27.1, C28.1, L20.2, R21.1, TP20.1; also elsewhere on the board
GND: C20.2, C21.2, C23.2, C24.2, C26.2, C27.2, C28.2, C30.2, C31.2, C33.2, C34.2, C36.2, C37.2, C38.2, R22.2, R32.2, U20.7 (GND), U20.9 (EP), U30.7 (GND), U30.9 (EP); also elsewhere on the board
unnamed: C23.1, R20.2
unnamed: C33.1, R30.2
unnamed: C22.1, U20.1 (BST)
unnamed: C24.1, R20.1, U20.6 (COMP)
unnamed: C25.2, R21.2, R22.1, U20.5 (FB)
unnamed: C21.1, U20.4 (SS)
unnamed: C22.2, L20.1, U20.8 (SW)
unnamed: C32.1, U30.1 (BST)
unnamed: C34.1, R30.1, U30.6 (COMP)
unnamed: C35.2, R31.2, R32.1, U30.5 (FB)
unnamed: C31.1, U30.4 (SS)
unnamed: C32.2, L30.1, U30.8 (SW)
VCC_BATT: C20.1, C30.1, U20.2 (VIN), U20.3 (EN), U30.2 (VIN), U30.3 (EN); also elsewhere on the board

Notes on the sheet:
C30: Low ESR C31: at least 10nF
Regulador 4.2V para SIM7600
Regulador 5V
C20: Low ESR C21: at least 10nF
C25, C35: NO-STUFF
C15,16,17: MLCC low ESR. 22 to 68 uF
For 4.2V output set R31 to 93.9k
C33: MLCC
C22: MLCC
Output 5.1V set R21 to 115.8k
PWR Flags

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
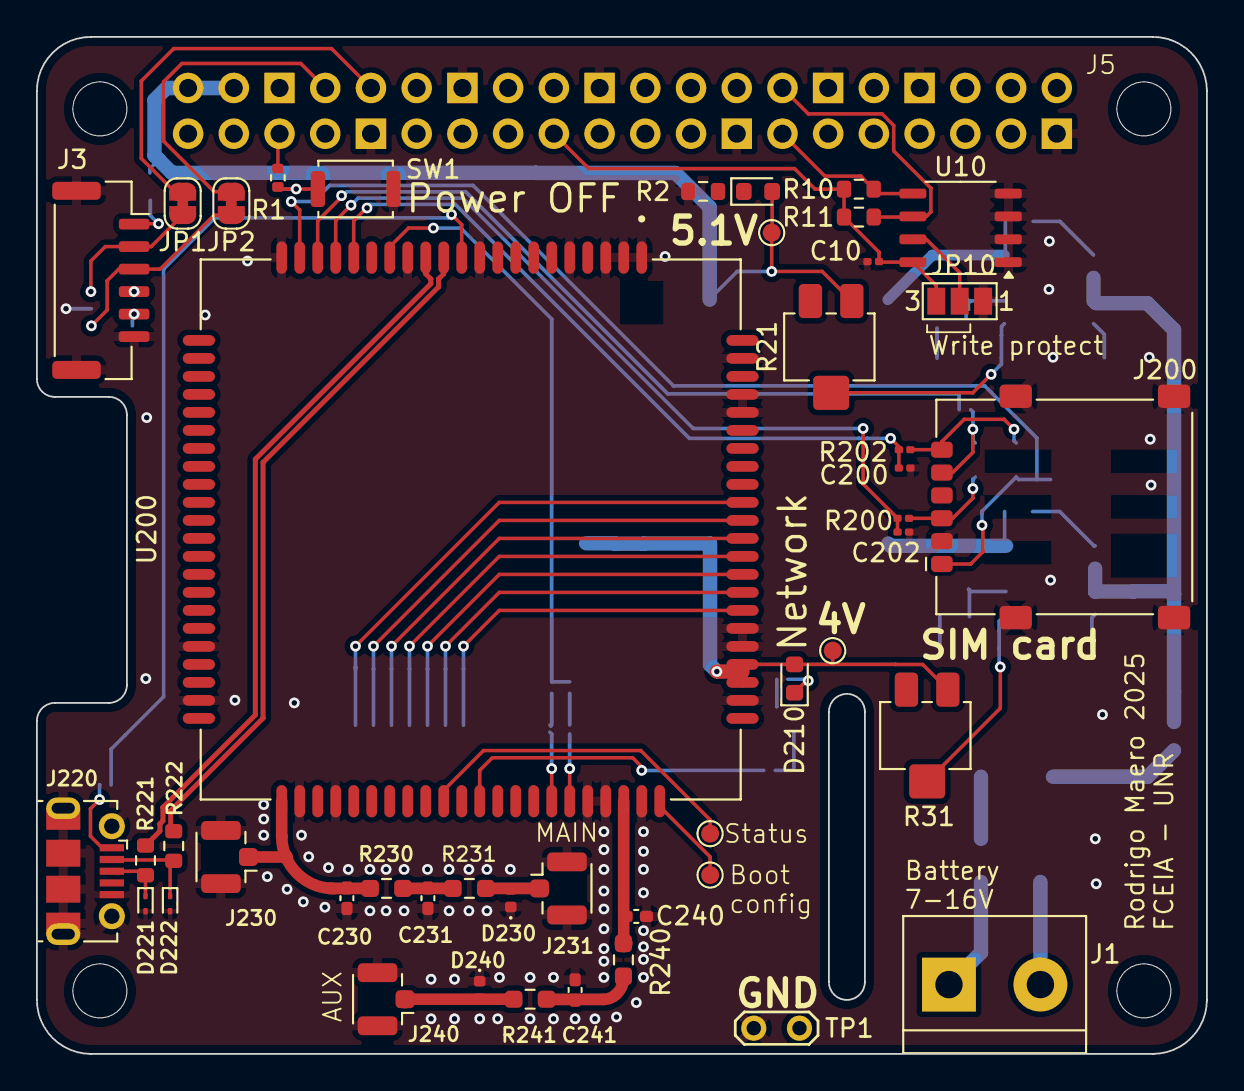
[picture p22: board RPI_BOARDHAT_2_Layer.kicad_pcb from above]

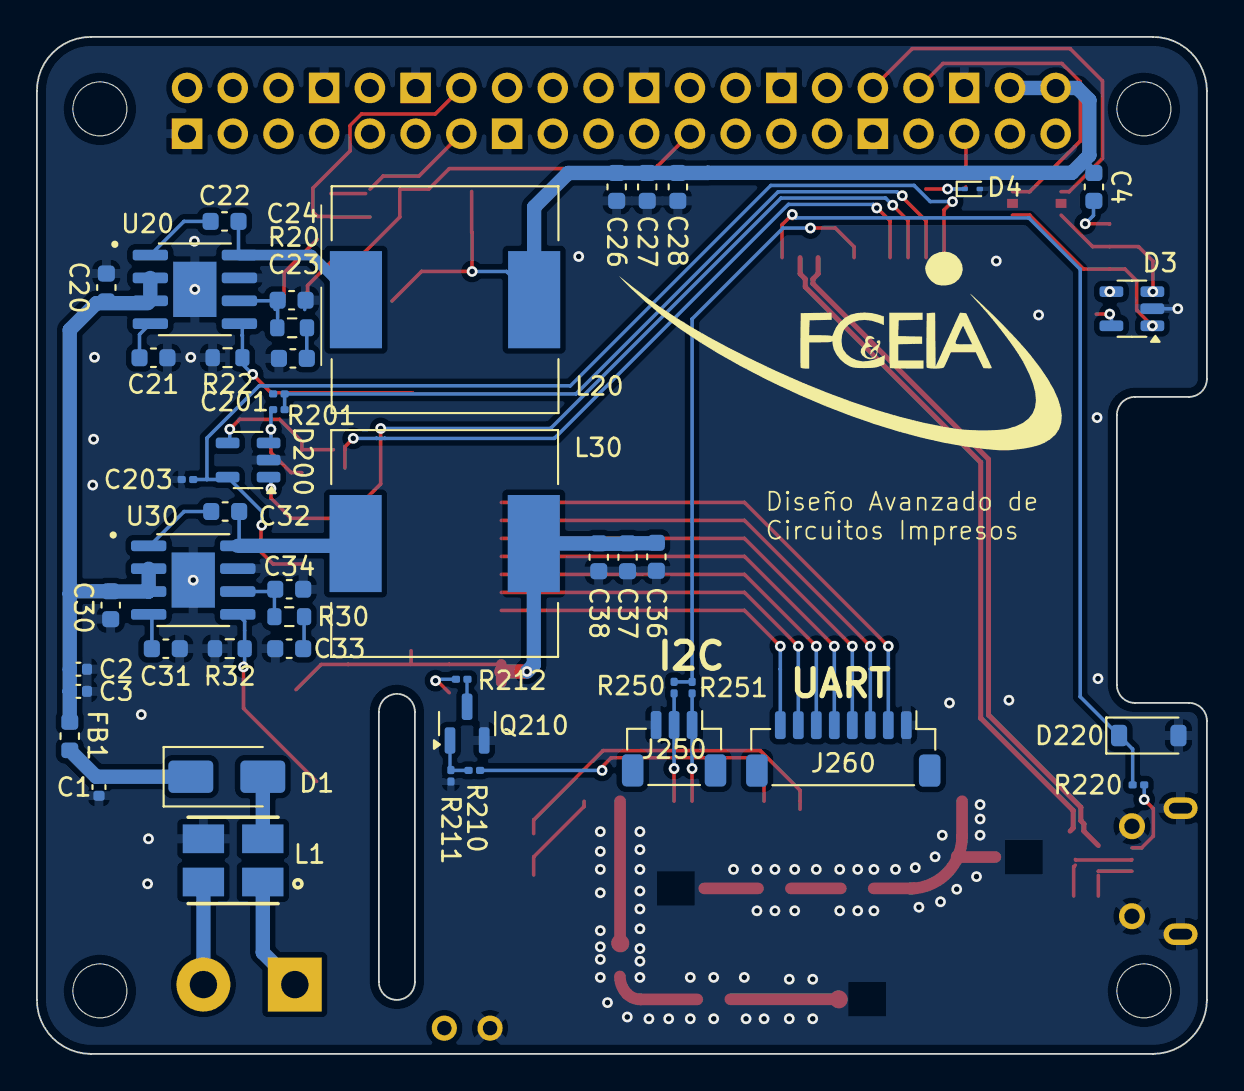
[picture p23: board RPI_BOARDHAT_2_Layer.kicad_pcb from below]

Board: 2 copper layers, 65.0 x 56.5 mm, 93 parts (47 on the bottom side), 69 nets.
